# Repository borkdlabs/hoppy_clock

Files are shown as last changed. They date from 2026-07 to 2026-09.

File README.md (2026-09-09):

# hoppy_clock






STM32-based alarm clock and RGB lamp: custom alarms wake you with light and your
own songs, configured over USB from the browser or a Python tool.

<a href="https://www.pcbway.com">
  PCBWay Logo
</a>

💚 Sponsored by **[PCBWay](https://www.pcbway.com)**, who provided the bare PCBs
and solder paste stencil for the v0.1.0-alpha boards -
see [Acknowledgements](#acknowledgements).

---

<details markdown="1">
  <summary>Table of Contents</summary>

<!-- TOC -->
* [hoppy_clock](#hoppy_clock)
  * [1 Overview](#1-overview)
    * [1.1 Bill of Materials (BOM)](#11-bill-of-materials-bom)
    * [1.2 Block Diagram](#12-block-diagram)
    * [1.3 Pin Configurations](#13-pin-configurations)
    * [1.4 Clock Configurations](#14-clock-configurations)
  * [2 Board Specifications](#2-board-specifications)
    * [2.1 Connectors](#21-connectors)
    * [2.2 Switches & Jumpers](#22-switches--jumpers)
    * [2.3 LEDs](#23-leds)
    * [2.4 Test Pads](#24-test-pads)
    * [2.5 Power Supply](#25-power-supply)
    * [2.6 Speaker](#26-speaker)
  * [3 Firmware](#3-firmware)
    * [3.1 User Button Controls](#31-user-button-controls)
    * [3.2 USB Configuration](#32-usb-configuration)
      * [3.2.1 Web App](#321-web-app)
      * [3.2.2 Python Tool](#322-python-tool)
    * [3.3 Light Looks](#33-light-looks)
    * [3.4 Sounds](#34-sounds)
    * [3.5 Firmware Update (DFU)](#35-firmware-update-dfu)
  * [4 Development](#4-development)
    * [4.1 Web App](#41-web-app)
    * [4.2 Deployment](#42-deployment)
  * [Acknowledgements](#acknowledgements)
  * [Third-Party Licenses](#third-party-licenses)
<!-- TOC -->

</details>

---

## 1 Overview

| Top | Bottom |
|:---:|:---:|
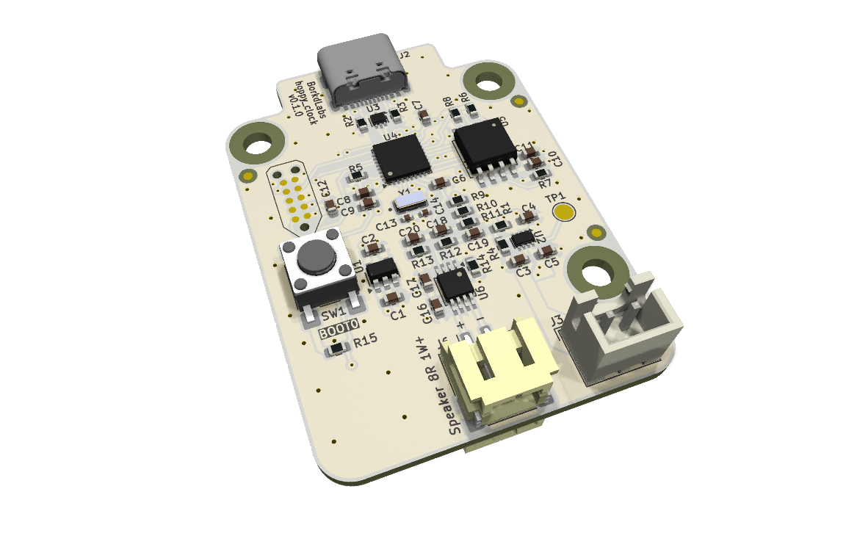
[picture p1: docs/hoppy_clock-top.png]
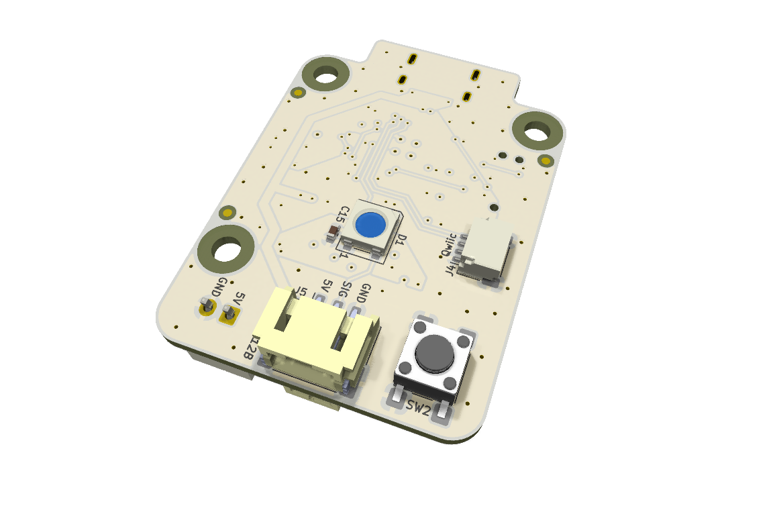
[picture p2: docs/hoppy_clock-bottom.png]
|  |  |

**Features**:

- ⏰ **Alarms**: up to 64, each either weekly (any set of weekdays) or monthly (a
  day of the month) at a chosen time. Every alarm has its own light look, sound,
  volume fade-in and auto-quiet timeout.
- 💡 **Lamp**: the single button toggles a warm lamp look on/off, the "off"
  state can settle to a dim ambient rather than fully dark.
- ✨ **Lights**: parametric looks (`solid`, `rainbow`, `sweep`, `breathe`)
  rendered across the onboard LED and any chained via the `WS2812B breakout`
  connector, every one of them with its own fade and optional flicker.
- 🔊 **Sounds**: two slots, ~4 minutes each at the default 16 kHz (16-bit PCM,
  sample rate is selectable up to 48 kHz), streamed from flash. Alarms play them
  with an optional fade-in.
- 🔋 **Low power**: the MCU sleeps between events and drops into STOP2 once the
  system is idle, waking on the next alarm or a button press (useful on backup
  supply).
- 🖥️ **Configuration**: nothing is hard-coded, the board takes its settings over
  USB from the [web app](https://borkdlabs.github.io/hoppy_clock/) (Chrome or
  Edge, nothing to install).
- 🔴 **Clock-unset cue**: if the time has never been set (for example, after a
  full power loss), the onboard LED (index 0) blinks dim red and alarms are
  blocked from triggering until the clock is set.

### 1.1 Bill of Materials (BOM)

| Manufacturer Part Number | Manufacturer | Description | Quantity | Notes |
|---|---|---|---:|---|
| STM32L432KC | STMicroelectronics  | 32-bit MCU | 1 | |
| WS2812B | (Various) | PWM Addressable RGB LED | 1 | |
| PAM8302AAS | Diodes Incorporated | Audio Amplifier | 1 | |
| W25Q128JVSIQ | Winbond Electronics | 128 Mbit NOR Memory | 1 | |
| Generic Push Button | | | 1 | |

### 1.2 Block Diagram

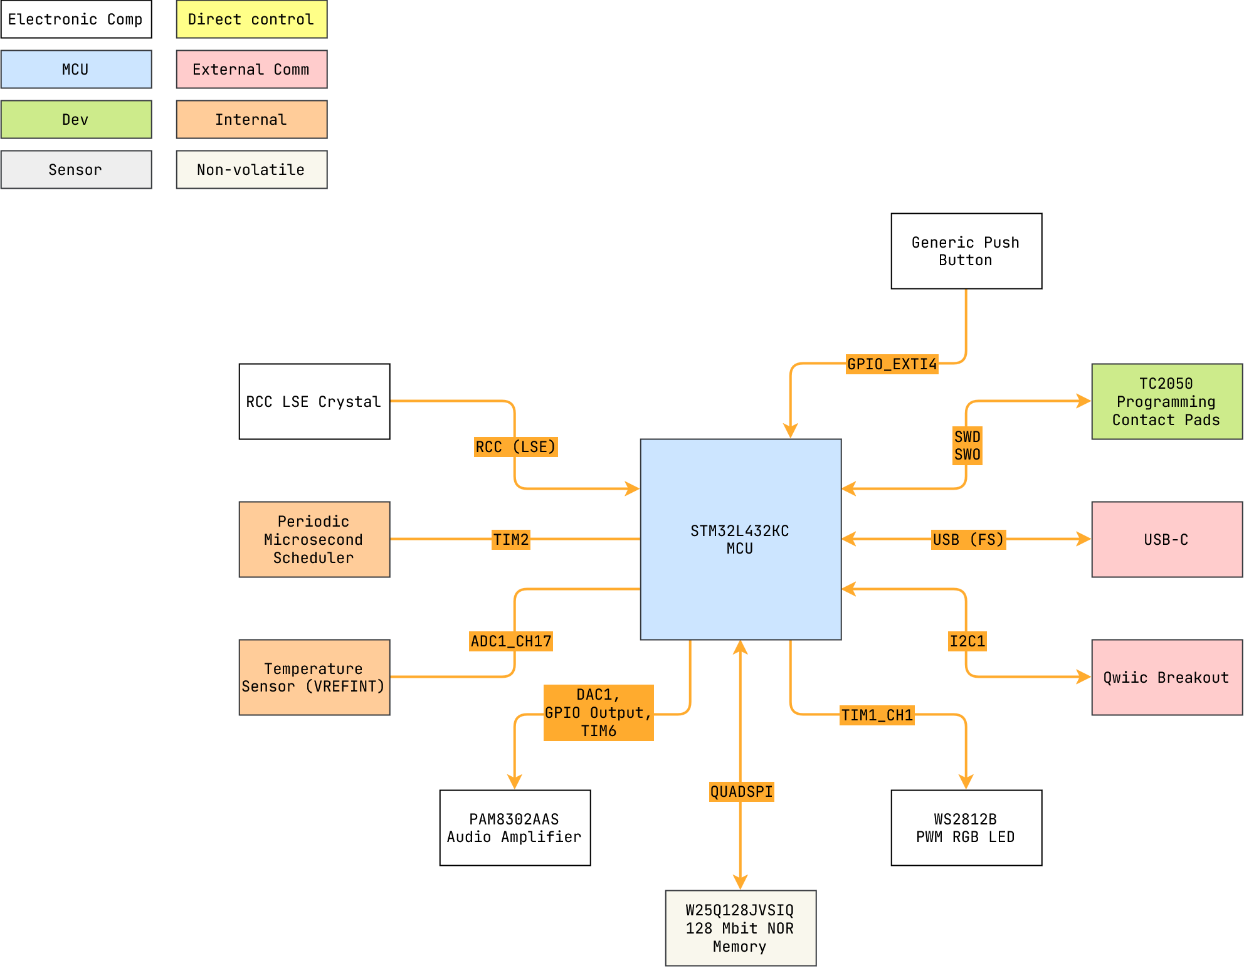
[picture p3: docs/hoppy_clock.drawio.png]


> Drawio file here: [hoppy_clock.drawio](docs/hoppy_clock.drawio).

### 1.3 Pin Configurations

<details markdown="1">
  <summary>CubeMX Pinout</summary>

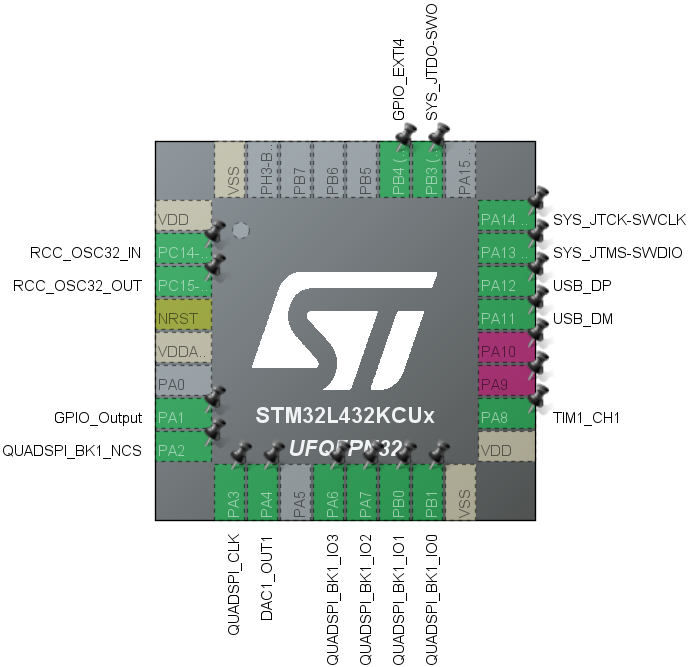
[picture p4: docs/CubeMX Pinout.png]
CubeMX Pinout.png


</details>

<details markdown="1">
  <summary>Pin & Peripherals Table</summary>

| STM32L432KC | Peripheral | Config | Connection | Notes |
|---|---|---|---|---|
| PA14 | `SYS_JTCK-SWCLK`  | | TC2050 SWD Pin 4: `SWCLK` | |
| PA13 | `SYS_JTMS-SWDIO`  | | TC2050 SWD Pin 2: `SWDIO` | |
| PB3 | `SYS_JTDO-SWO` | | TC2050 SWD Pin 2: `SWO` | |
| | `TIM2_CH1` | PWM no output | Scheduling | Scheduler timer. |
| | `TIM6` | TRGO update event | | `DAC1_OUT1` TRGO. |
| | `ADC1` `VREFINT`  | Scan conversion mode | VDDA Sense | Configured in ADC1 rank 1. |
| | `ADC1_IN17` | Scan conversion mode | Temperature Sensor Channel | Configured in ADC1 rank 2. |
| PA10 | `Reserved` | 115200 bps | GPIO Breakout: (ie Qwiic: `I2C1_SDA`) | Reserved GPIO breakout (PA10). |
| PA9 | `Reserved` | 115200 bps | GPIO Breakout: (ie Qwiic: `I2C1_SCL`) | Reserved GPIO breakout (PA9). |
| PA11 | `USB_DM` | Device (FS) | USB-C D- | |
| PA12 | `USB_DP` | Device (FS) | USB-C D+ | |
| PA8 | `TIM1_CH1` | PWM Generation CH1 | WS2812B-2020 Pin: `DIN` | DIN pin number depends on IC variant. |
| PA4 | `DAC1_OUT1` | | PAM8302AAS Input Circuit | |
| PA1 | `GPIO_Output` | Hardware pull-down | PAM8302AAS Pin 1: `SD` | |
| PA3 | `QUADSPI_CLK` | | W25Q128JVSIQ Pin 6: `CLK` | |
| PA2 | `QUADSPI_BK1_NCS` | Hardware pull-up | W25Q128JVSIQ Pin 1: `CS` | |
| PB1 | `QUADSPI_BK1_IO0` | | W25Q128JVSIQ Pin 5: `IO0` | |
| PB0 | `QUADSPI_BK1_IO1` | | W25Q128JVSIQ Pin 2: `IO1` | |
| PA7 | `QUADSPI_BK1_IO2` | Hardware pull-up | W25Q128JVSIQ Pin 3: `IO2` | Hardware pull-up for potential bringup from SPI single-line. |
| PA6 | `QUADSPI_BK1_IO3` | Hardware pull-up | W25Q128JVSIQ Pin 7: `IO3` | Hardware pull-up for potential bringup from SPI single-line. |
| PB4 | `GPIO_EXTI4` | Hardware pull-up | Generic Push Button Active Low pin | |

</details>

### 1.4 Clock Configurations

```
4 MHz Multi-Speed Internal (MSI), LSE-trimmed
 -> Phase-Locked Loop Main (PLL)
 -> 80 MHz SYSCLK
 -> 80 MHz HCLK
     -> 80 MHz APB1 (Maxed) -> 80 MHz APB1 Timer
     -> 80 MHz APB2 (Maxed) -> 80 MHz APB2 Timer
 -> PLLSAI1 -> 48 MHz USB & ADC clock

32.768 kHz Low Speed External (LSE)
     -> 32.768 kHz RTC
     -> Disciplines the MSI (MSI PLL mode)
```

---

## 2 Board Specifications

### 2.1 Connectors

Connectors fixed by hardware (PCB traces or the connector itself).

| Connector | Ref | Description |
|---|:---:|---|
| `Tag-Connect TC2050` | J1  | SWD programming/debug connector |
| `USB-C` | J2  | USB-C 5 V power & data source |
| `Backup supply` | J3  | 1x2 JST XH (2.5 mm pitch), Pin 1: Backup 5 V, Pin 2: ground |
| `Qwiic` | J4  | 1x4 JST SH, Pin 1: ground, Pin 2: 3.3 V, Pin 3: SDA, Pin 4: SCL |
| `WS2812B breakout` | J5  | 1x3 JST PH, Pin 1: 5 V, Pin 2: DOUT, Pin 3: ground |
| `Speaker` | J6  | 1x2 JST PH, Pin 1: OUT+, Pin 2: OUT- |

### 2.2 Switches & Jumpers

User controllable hardware and/or firmware driven inputs.

| Switch/Jumper  | Ref | Description |
|---|:---:|---|
| `BOOT0 button` | SW1 | Push to pull `BOOT0` high |
| `User button`  | SW2 | Generic 6 mm SMD button |

### 2.3 LEDs

LEDs used to show board status and/or user controllable.

| LED | Mark | Description |
|---|---|---|
| `WS2812B LED` | None | RGB addressable LED |

### 2.4 Test Pads

| Test Point | Ref | Description |
|---|:---:|---|
| `TPS2116 ST` | TP1 | `ST` pin from onboard TPS2116 |

### 2.5 Power Supply

By default, the board is powered from the `USB-C` 5 V source. An onboard TPS2116
priority power mux allows a backup 5 V supply to be connected via the
`Backup supply` connector (for example, a regulated battery pack output). If the
USB-C supply drops below the mux threshold, the TPS2116 automatically switches
the board over to the backup supply and switches back when USB-C power returns.
The mux status pin (`ST`) is exposed on the `TPS2116 ST` test pad and is pulled
low whenever the backup supply is in use, allowing a probe to detect the active
source during development/testing.

TPS2116 4.1 V switchover threshold logic:

```
PR1 = VIN1 * R_bot / (R_top + R_bot)
    = VIN1 * 220k / (680k + 220k)
    = VIN1 * 0.2444

VIN1(th) = 1V * (R_top + R_bot) / R_bot
         = 1V * (680k + 220k) / 220k
         = 4.09 V

Tolerance: +-0.08V
min: (1V - 0.08V) * 4.0909 = 3.76 V
max: (1V + 0.08V) * 4.0909 = 4.42 V
```

External LEDs on the `WS2812B breakout` connector are powered from USB (VBUS)
directly, not the priority power mux in order to prevent excessive battery drain
during a power outage. The single onboard LED is on the priority power mux
supply, so it remains available for minimum operation on battery power.

### 2.6 Speaker

An 8 ohm, >= 1 W speaker can be connected via the `Speaker` connector. The
amplifier output is bridge-tied (BTL): both terminals are driven, so neither may
be connected to ground.

---

## 3 Firmware

The firmware is fixed, all user settings (time, alarms, light looks, the lamp,
sounds and the LED count) live in the W25Q NOR flash and are written over USB at
runtime. Settings survive resets (the clock's time is kept in the STM32 backup
domain), as long as the board stays powered from USB-C or the backup supply. A
full power loss resets the clock (see the clock-unset cue above). A flash `wipe`
returns the unit to a clean state.

Stored settings carry a format version. A firmware update that changes that
format resets them: rather than misread an older image, the board falls back to
empty defaults, comes up on its built-in lamp look and needs reconfiguring.

### 3.1 User Button Controls

| Action | While idle | While an alarm is ringing |
|---|---|---|
| Short press | Toggle the lamp on/off | (ignored) |
| Long press  | Play / stop the button song | Silence the alarm |

### 3.2 USB Configuration

The board enumerates as a USB CDC virtual serial port and speaks a small framed
command protocol (`firmware/Core/Inc/usb_cmd.h`). Two hosts implement it:

| Host | Runs on |
|---|---|
| [`software/main.py`](software/main.py) | Any OS with Python 3 |
| [Web app](https://borkdlabs.github.io/hoppy_clock/) | Chrome or Edge on desktop, no install |

Both open the same serial port and only one program may hold it at a time.

**Connecting:** When the clock is idle and off USB it deep-sleeps (STOP2) and
deliberately presents as *detached*, so plugging into a host shows no device at
first. To connect:

1. Plug the USB-C cable into the host.
2. **Press the button once** to wake the clock. It re-attaches and enumerates as
   a virtual serial port (the same short press also toggles the lamp as usual,
   harmless).
3. Run the Python tool.

If the clock is already awake (in use, ringing, an alarm just fired, or the lamp
is showing a continuously animating look), it enumerates the moment you plug in,
with no press needed. Unplugging or the host going to sleep allows the system to
return to deep sleep.

> **Why a button press?** The clock cannot tell a data host (a PC) from a plain
> USB-C charger or power bank, both simply present 5 V with no reliable way to
> distinguish them until an enumeration that only a real host answers. Waking
> and enumerating on every plug-in would spend energy for the majority of the
> time the port is used only to charge or power the unit and risks staying awake
> on a battery pack it mistook for a host. Gating USB behind a deliberate button
> press ties enumeration to a real intent to configure and lets the clock stay
> in its lowest-power state whenever it is merely being powered. Firmware itself
> is flashed over SWD (the `TC2050` header), independent of this path.

#### 3.2.1 Web App

<https://borkdlabs.github.io/hoppy_clock/>

A single static page that drives the port through the
[Web Serial API](https://developer.mozilla.org/en-US/docs/Web/API/Web_Serial_API),
so there is nothing to install beyond the OS's own CDC driver. It needs **Chrome
or Edge on desktop** (Windows, macOS or Linux); Firefox, Safari and mobile
browsers do not implement Web Serial and the page says so rather than
half-working.

Press *Connect* and pick the STM32 virtual COM port (`0483:5740`). Permission is
granted per site and remembered, so later visits reopen that port on their own.

#### 3.2.2 Python Tool

```bash
cd software
python main.py <command> [options]     # add -p COM7 (or /dev/ttyACM0) to pick the port
```

> Needs Python 3 with `pyserial` (`pip install -r software/requirements.txt`),
> MP3 uploads additionally need `ffmpeg` on the `PATH`. See top docstring in
> `main.py` for more information.

| Command | Description |
|---|---|
| `set-time` | Sync the RTC to the host's local time |
| `add-alarm` / `set-alarm` | Add an alarm (e.g. `--at 08:00 --days weekdays`) / replace all with one |
| `remove-alarm N` / `clear-alarms` | Delete one alarm by index / delete all |
| `list-alarms` | Show alarms, lights, the lamp and LED count |
| `set-light` | Define a light look (`--effect`, `--fade`, `--curve`, `--flicker`) |
| `set-lamp` | Choose the on/off lamp idle looks |
| `set-led-count N` | Set the number of chained LEDs |
| `upload-sound` | Store a sound from a WAV/MP3 file or a synthesized tone |
| `play-sound` / `stop-sound` | Play / stop a stored sound now |
| `set-button-song` | Set which sound the long-press plays |
| `wipe` | Factory-reset the flash (`--full` also scrubs the audio) |

Run `python main.py --help` (or `<command> --help`) for the full option list.

### 3.3 Light Looks

A light look is not a stored animation but a handful of parameters the firmware
renders live across the whole chain. Up to 16 are stored; alarms and the two
lamp idle states each reference one by id. Every look sets a base colour and a
master brightness, then picks an effect:

| Effect | Renders | Cycle time | Spread |
|---|---|---|---|
| `solid` | The whole strip held at one colour  | - | - |
| `rainbow` | The HSV hue wheel, cycling | Time per turn | Hue step per LED (0 = strip as one colour) |
| `sweep` | A lit band travelling over darkness | Time per pass | Band width, in LEDs |
| `breathe` | The colour swelling and receding | Time per breath | - |

`solid` settles and holds as an idle. The other three loop until something else
is played.

The same three settings apply to all four alike:

| Setting | Does |
|---|---|
| `fade` | Time this look takes to fade in over whatever is already lit |
| `curve` | Shape of that fade: `linear` (constant rate) or `ease` (gentle at both ends) |
| `flicker` | Amplitude of a random brightness dip, redrawn several times a second |

**A fade runs on entry only.** Every transition uses the fade of the look
arriving, never of the one leaving: playing a look is the only thing that starts
a fade, and by then the previous look is already on its way out. So the `fade`
on a `rainbow` decides how that rainbow appears and has no say in what happens
when something later replaces it.

To fade a look both in and out, set the fade on that look **and** on whatever
replaces it. A lamp that eases up and back down over two and a half seconds:

| Look | Effect | Brightness | Fade | Curve  |
|---|---|---|---|---|
| Lamp on  | `rainbow` | 200 | 2500 | `ease` |
| Lamp off | `solid` | 0 | 2500 | `ease` |

Give the lamp-off look a fade of 0 instead, and it cuts to black the instant the
button is pressed, no matter how long the rainbow's own fade is. A fade of 0
always means "no fade, show this look now".

The look being faded away from is held as a still frame, so a `rainbow` stops
cycling the moment it is replaced and dims from whichever hues it had reached.

Flicker is a texture rather than a shape, so it is set separately from the
curve, and the two combine freely. Unlike the fade it never ends, which is what
makes a `solid` warm white read as a candle instead of a lamp.

**A continuously animating look keeps the board out of deep sleep.** Only a
`solid` look with `flicker` 0 ever finishes: once its fade lands, it settles on
a fixed colour, stops rendering, and lets the MCU drop into STOP2. `rainbow`,
`sweep` and `breathe` loop for as long as they are showing, and any `flicker`
above 0 never stops, so a look of either kind holds the board in light sleep
instead. Two consequences follow:

- **Power.** Light sleep gates the core but keeps the clocks and peripherals
  live, so the board sits at run current rather than the microamps STOP2 draws.
  That matters most on the backup supply, where a permanently animated lamp look
  is a far heavier load than a settled `solid` one.
- **USB.** A board that never deep-sleeps never detaches either, so it
  enumerates the moment it is plugged in with no button press needed (see
  [3.2 USB Configuration](#32-usb-configuration)). Parking the lamp on an
  animated look is a way to keep it permanently connectable while configuring.

The clock-unset warning blink holds the board awake in the same way, until the
time is set.

### 3.4 Sounds

Two slots hold one sound each, 7.5 MiB apiece, in the same NOR flash as the
settings. Alarms reference a slot by id, and the long press plays one.

**The source file's own format does not matter.** Uploading anything that is not
already raw PCM runs it through `ffmpeg`, which decodes and resamples it to mono
at the rate and sample format *you* pick:

```bash
ffmpeg -i song.mp3 -ac 1 -ar <rate> -f s16le|u8 -
```

A 320 kbps 44.1 kHz stereo MP3 and a 96 kbps mono one land on the board as the
same shape of data, so there is nothing to read off a file to decide with. What
gets stored is the raw blob plus the rate and format it was made at, the
firmware reads those back at playtime and clocks the DAC accordingly.

So the two settings are a trade between quality and how much fits in a slot:

| Rate | `s16` (2 B/sample) | `u8` (1 B/sample) |
|---|---|---|
| 8000 | 8m 11s | 16m 23s |
| 16000 (default) | 4m 05s | 8m 11s |
| 22050 | 2m 58s | 5m 56s |
| 32000 | 2m 02s | 4m 05s |
| 48000 (max) | 1m 21s | 2m 43s |

Two things to weigh:

- **The speaker is the real ceiling.** Output is a 12-bit DAC into a PAM8302A
  driving a little speaker, so 16 kHz already covers about as much bandwidth as
  it can reproduce. Higher rates mostly spend slot space on detail that never
  reaches the air.
- **`u8` halves the size but adds hiss.** Eight-bit quantization is audible on
  anything sustained. It suits short effects and tones, not music.

In practice leave both on their defaults (`s16` at 16000 Hz) and use the trim
option to fit a long track, rather than dropping quality to make it fit. Reach
for `u8` or a lower rate only when a long clip matters more than how it sounds.

### 3.5 Firmware Update (DFU)

This flashes new *firmware* (not settings, those use the USB tool above).
Normally firmware is programmed over SWD (the `TC2050` header). Without a
debugger, the STM32L432's built-in USB bootloader (DFU) flashes it over the same
USB-C port.

`BOOT0` is sampled only at power-up, so DFU has to be entered on a fresh cold
boot with the button held:

1. **Remove all power**, unplug USB **and** anything on the `Backup supply`
   connector. A backup supply keeps the MCU running, so plugging in USB would
   not be a cold boot and `BOOT0` would never be re-sampled. (With no backup
   supply attached, USB is the only source and this is automatic.)
2. Hold the `BOOT0` button.
3. While still holding it, connect USB-C to the computer. The board powers up
   into the bootloader and enumerates as **STM32 BOOTLOADER** (DFU, USB
   `0483:DF11`). Release the `BOOT0` button.
4. Flash the image to the flash base `0x08000000`, then restart into it with
   your DFU tool/software.

---

## 4 Development

### 4.1 Web App

[`webapp/`](webapp) is plain ES modules with no build step, no bundler and no
dependencies, it is served exactly as it sits in the repository. Web Serial only
runs in a secure context and `http://localhost` counts as one, so a static
server is enough and no HTTPS setup is needed:

```bash
cd webapp
python -m http.server 8000
```

Then open <http://localhost:8000> in Chrome or Edge.

| Path | What it is |
|---|---|
| `index.html`, `css/style.css` | Page and styling |
| `js/alarms.js` | Packed alarm records, mirrors `manifest.h` |
| `js/app.js` | Tab switching and the wiring behind every card |
| `js/device.js` | Port lifecycle, transactions, manifest read/write |
| `js/lights.js` | Packed light looks, mirrors `manifest.h` |
| `js/sounds.js` | Sound slots and the decode/encode upload path |
| `js/protocol.js` | Framing and CRC-8, mirrors `firmware/Core/Inc/usb_cmd.h` |
| `dev/` | The helpers below, stripped from the published site |

**Working without a board.** The offline checks exercise the framing and
transaction layers against a fake CDC port, covering the happy path, error
statuses, command timeouts and a mid-command unplug:

```bash
cd webapp/dev
node test-device.mjs
```

For the UI itself, paste
[`dev/inject-fake-port.js`](webapp/dev/inject-fake-port.js) into the browser
console with the page open. It stubs `navigator.serial.requestPort` with a clock
whose RTC runs 47 s fast, so the connect flow, the drift readout and the sync
button can all be driven dry. More in [`webapp/dev/`](webapp/dev/README.md).

A protocol change touches three implementations, keep them in step:
`firmware/Core/Inc/usb_cmd.h`, `software/main.py` and `webapp/js/`
(`protocol.js` for the framing, `alarms.js`, `lights.js` and `sounds.js` for the
record layouts).

### 4.2 Deployment

[`.github/workflows/pages.yaml`](.github/workflows/pages.yaml) publishes the app
to GitHub Pages on every push to `main` touching `webapp/`. It runs
`node --check` over each module and the offline checks above, copies `webapp/`
to the site root minus `dev/`, then deploys. Pull requests build and test but do
not publish and the workflow can also be started by hand (*Actions -> Pages ->
Run workflow*).

The repository's Pages source must be set to **GitHub Actions**
(*Settings -> Pages -> Build and deployment -> Source*).

---

## Acknowledgements

<a href="https://www.pcbway.com">
  PCBWay Logo
</a>

This project is sponsored by [PCBWay](https://www.pcbway.com), whose PCB
manufacturing services are essential in producing high-quality prototypes for
its development. Their support ensures reliable boards that meet the project's
demands.

**Why PCBWay?**

PCBWay stands out for their exceptional services and commitment to the
community:

- **PCB manufacturing**: multilayer, rigid-flex and other advanced fabrication.
- **PCB assembly**: soldering, component sourcing and assembly.
- **Other services**: CNC machining and 3D printing, for projects that need more
  than a board.
- **Fast turnaround**: quick production times that keep a project on schedule.
- **Open source and education**: they sponsor projects and publish tutorials,
  videos and documentation for developers and hobbyists.
    - This commitment to education and open-source advocacy was a key factor in
      choosing them as a partner 🙂.

Their dedication to professional-grade services and fostering innovation makes
PCBWay an invaluable partner in bringing this project to life.

---

## Third-Party Licenses

This project uses the following open-source software components:

- **STM32Cube HAL**, STMicroelectronics.
    - Licensed under the `3-Clause BSD License`.
        - See
          [`LICENSE.txt`](firmware/Drivers/STM32L4xx_HAL_Driver/LICENSE.txt).

> STMicroelectronics are trademarks of their respective owners. Use of these
> names does **not** imply any endorsement by the trademark holders.

> The PCBWay name and logo are trademarks of PCBWay, reproduced with their
> permission to acknowledge their sponsorship of this project.

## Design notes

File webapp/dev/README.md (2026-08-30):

# Development helpers

Not part of the deployed site, the Pages workflow strips this directory before
publishing.

## Serve the app locally

Web Serial needs a secure context, and `http://localhost` counts as one, so no
HTTPS setup is required:

```bash
cd webapp
python -m http.server 8000
```

Then open <http://localhost:8000> in Chrome or Edge.

## `test-device.mjs`

Exercises the framing, transaction and manifest layers against a fake CDC port,
with no hardware attached. Covers the happy path, error statuses, command
timeouts, mid-command unplug, the packed alarm, light and sound records, and
editing alarms, light looks, the lamp ids, the LED count and the button song
without disturbing the rest of the manifest. Sound upload is covered too: PCM
encoding, a CRC-32 check against a known vector, the chunked stream arriving
byte for byte, and a cancel part-way leaving nothing committed. Clearing the
alarm table, lighting a single LED, and both wipe scopes are covered too.

```bash
cd webapp/dev
node test-device.mjs
```

## `inject-fake-port.js`

Paste into the browser console (or evaluate through DevTools) while the app is
open. It replaces `navigator.serial.requestPort` with a stub clock whose RTC
runs 47 s fast, whose manifest holds two alarms and two light looks, and whose
first sound slot holds a 10 s blob, so every tab can be driven without a board.
It accepts uploads and wipes as well: playback commands land on
`window.__lastPlayback` rather than making a noise, a committed upload lands on
`window.__lastUpload`, a wipe on `window.__lastWipe`, and a lit LED on
`window.__lastLed`. The stub's manifest is left on
`window.__fakeConfig`, which is the quickest way to see what a save actually
wrote.

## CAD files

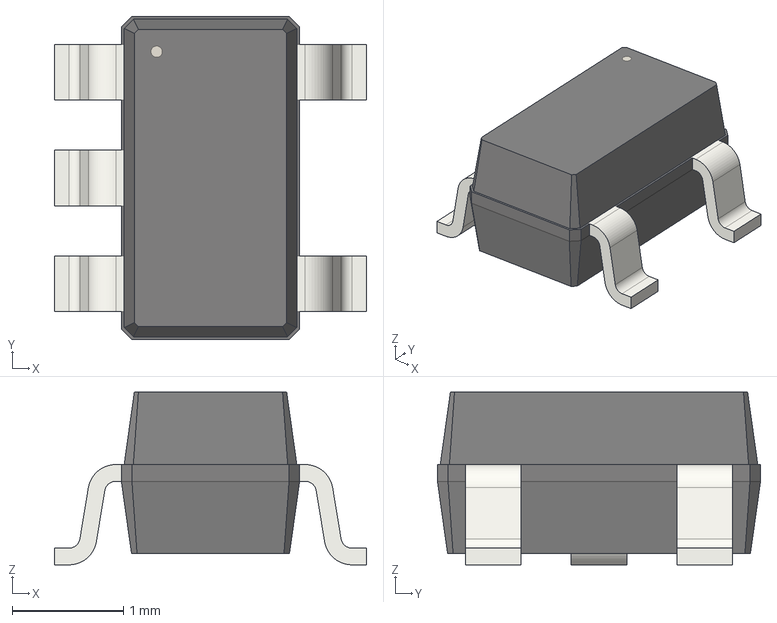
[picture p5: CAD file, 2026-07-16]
hardware/component_local/model_3d/0_standard/SOT-23-5.step
2.80 x 2.90 x 1.55 mm

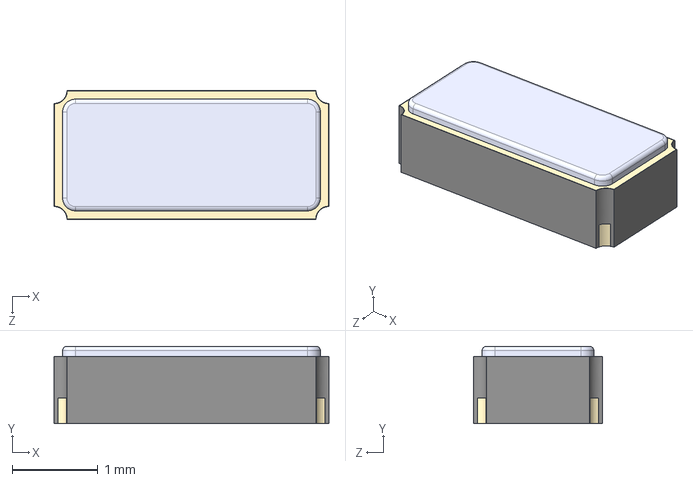
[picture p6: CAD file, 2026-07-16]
hardware/component_local/model_3d/common/ecs_ecx-34r.step
3.20 x 0.9 x 1.50 mm

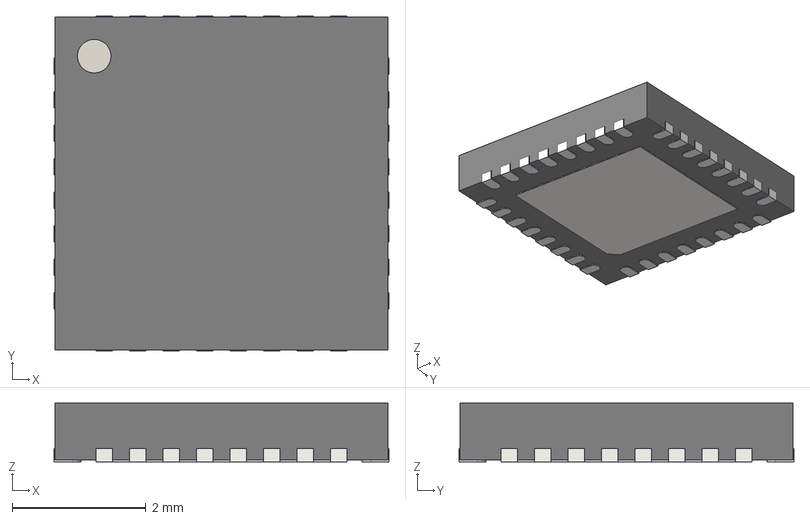
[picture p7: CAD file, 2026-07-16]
hardware/component_local/model_3d/stm32l4/QFN-32-1EP_5x5mm_P0.5mm_EP3.3x3.3mm.step
5.00 x 5.00 x 0.875 mm

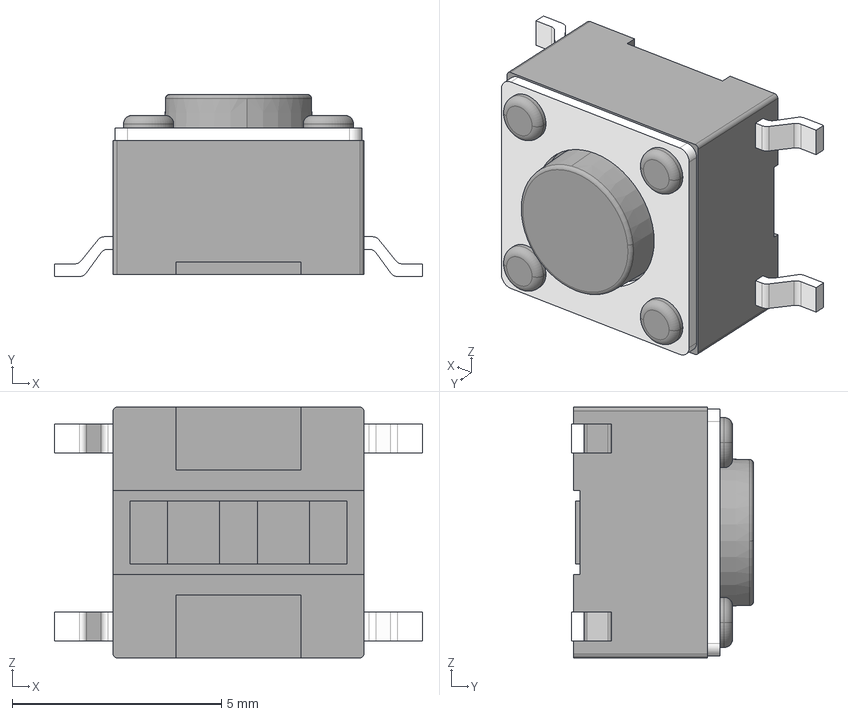
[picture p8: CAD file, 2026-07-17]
hardware/component_local/model_3d/switch/swt0310-043025gsa.stp
8.80 x 4.35 x 6.00 mm

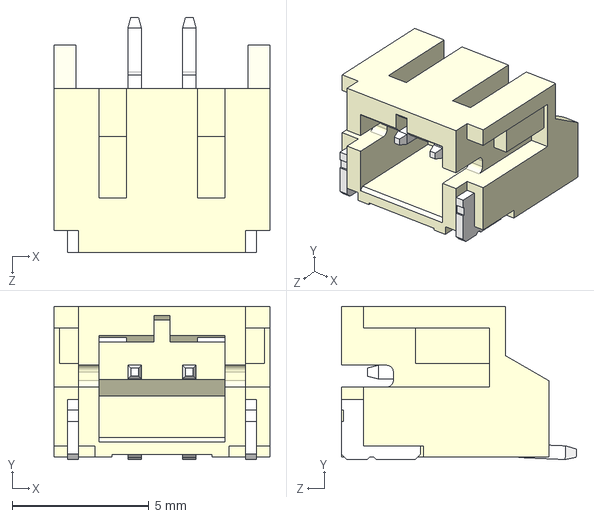
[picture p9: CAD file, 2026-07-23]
hardware/component_local/model_3d/z_other/S2B-PH-SM4-TB.STEP
7.90 x 5.60 x 8.60 mm

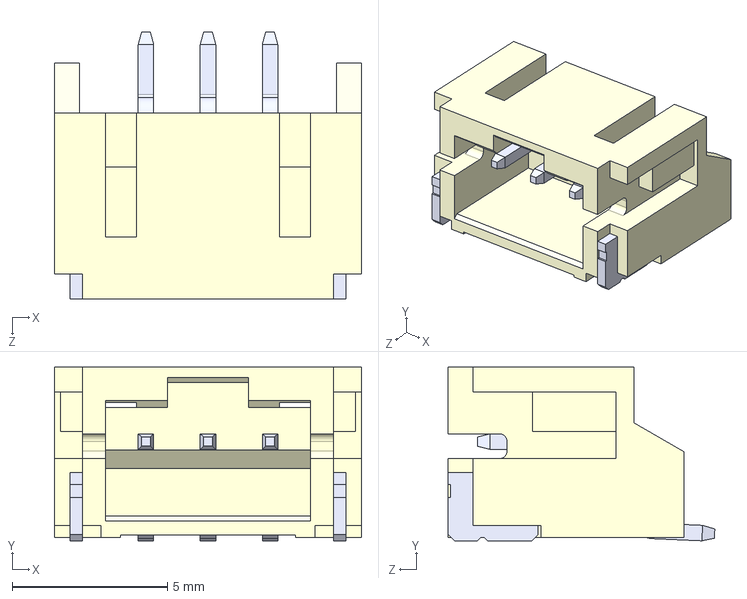
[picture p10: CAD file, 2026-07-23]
hardware/component_local/model_3d/z_other/S3B-PH-SM4-TB.STEP
9.90 x 5.60 x 8.60 mm

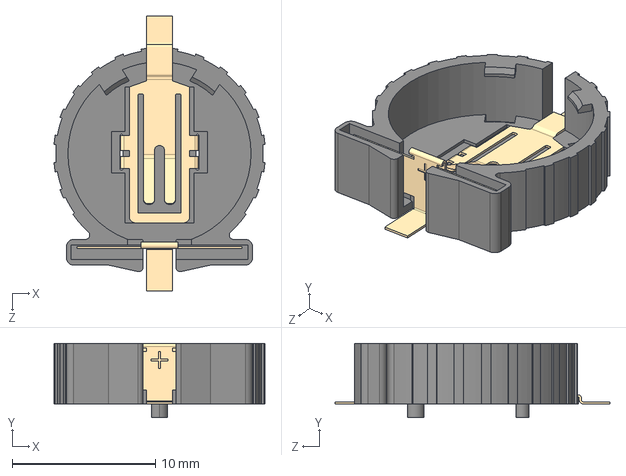
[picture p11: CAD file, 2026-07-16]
hardware/component_local/model_3d/common/S8411-45R.step
14.7 x 5.20 x 19.2 mm

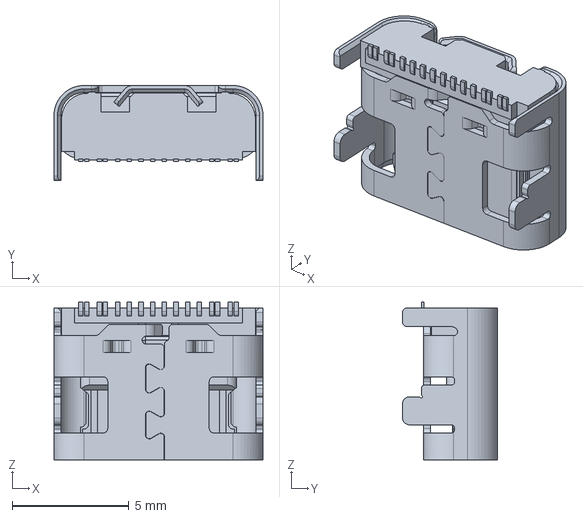
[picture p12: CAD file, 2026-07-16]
hardware/component_local/model_3d/common/2171790001.stp
8.94 x 4.06 x 6.75 mm

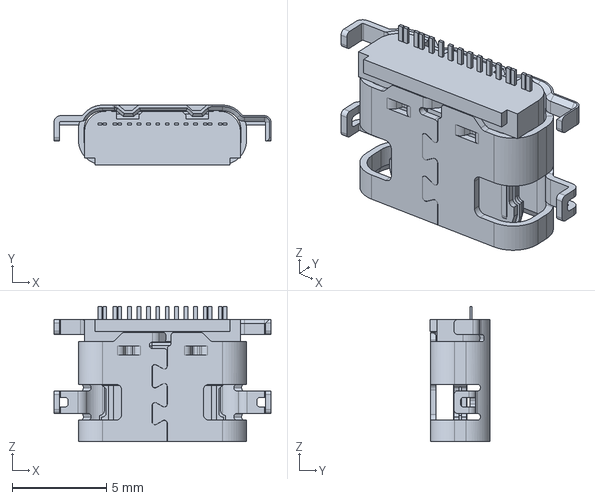
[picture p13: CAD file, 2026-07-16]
hardware/component_local/model_3d/common/2169900001.stp
11.5 x 3.18 x 7.20 mm

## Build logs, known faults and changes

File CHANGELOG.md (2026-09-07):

# Changelog

---

<details markdown="1">
  <summary>Table of Contents</summary>

<!-- TOC -->
* [Changelog](#changelog)
  * [v0.1.0-alpha (2026-07-25)](#v010-alpha--2026-07-25-)
  * [v0.1.0 (TBD)](#v010--tbd-)
<!-- TOC -->

</details>

---

## [v0.1.0-alpha (2026-07-25)](https://github.com/borkdlabs/hoppy_clock/releases/tag/v0.1.0-alpha)

- Pre-release 4-layer board variant (hardware-focused release).
    - Short-term pre-release board bring-up/testing release.
- Order date: 2026/07/21.
    - Note: Minor DNP status changes are included (changes made after order
      placement and before official release). No Gerber files are affected.

Manual corrections:

1. The silkscreen labeling the pins on the `WS2812B breakout` connector is
   incorrect (**_5 V and ground are flipped!_**). The true pinout is: 1x3 JST
   PH, Pin 1: ground, Pin 2: DOUT, Pin 3: 5 V.
    - The silkscreen represents the intended design (matching most WS2812B LED
      strip pinouts), but the connector pinout was ordered incorrectly. To be
      corrected in the following release.
2. The backup supply via the `Backup supply` connector should not be used unless
   jumpered.
    - The TPS2116DRL is missing something to help pull VIN1 low below the 1 V
      threshold in time of a supply switchover, leading to power issues when
      connecting to `Backup supply`. Manual fixes from quickest to best:
        1. Add a resistor light pull-down to VIN1 allowing a reliable drop of
           VIN1 to below 1 V.
        2. Add a divider circuit for a custom threshold:
            - Rewire PR1 as the divider center tap.
            - MODE to VIN1 directly (currently tied to VIN1 through PR1 pad)
            - Tested with a 76.8k / 22.1k divider (4.48 V threshold, less ideal
              due to very little upper tolerance).
3. _Optional_: The `WS2812B breakout` is currently wired to supply external
   off-board WS2812B LEDs using the TPS2116DRL post-mux supply. Cut the 3
   thermal relief traces on the 5 V net of the `WS2812B breakout` and jumper
   wire to the USB (VBUS) pour to prevent excessive backup supply drain.

---

## [v0.1.0 (TBD)](https://github.com/borkdlabs/hoppy_clock/releases/tag/v0.1.0)

- 4-layer board variant.
    - Moderate confidence near production release.
- **Modifications:**
    - Fix `WS2812B breakout` connector pinout to match silkscreen and expected
      WS2812B LED strip pinouts.
        - Update `README.md` docs accordingly.
    - Minor silkscreen cleanup.
    - Fix power switching, add voltage divider on TPS2116DRL for an improved
      supply mux threshold.
        - Previously used the default 1 V threshold.
        - VIN1 to 680k / 220k to ground voltage divider for 4.1 V threshold.
            - Pin PR1 disconnected from VIN1, center-tapped to voltage divider.
            - Pin MODE disconnected from PR1/VIN1, retraced directly to VIN1.
    - Add copper clearance on the top layer below the USB-C connector.
    - Add 1 mm fillet on USB-C area neck.
    - Fix the bad release link in `CHANGELOG.md` for v0.1.0-alpha.
    - Swap THT `User button` to match onboard `BOOT0 button` SMD part.
    - Move SMD right angle connectors `WS2812B breakout` and `Speaker` closer to
      edge cut for better wiring.
    - Split the `WS2812B breakout` to supply external off-board WS2812B LEDs via
      USB (VBUS) only to prevent excessive backup supply drain.
- Order date: **_TBD_**.

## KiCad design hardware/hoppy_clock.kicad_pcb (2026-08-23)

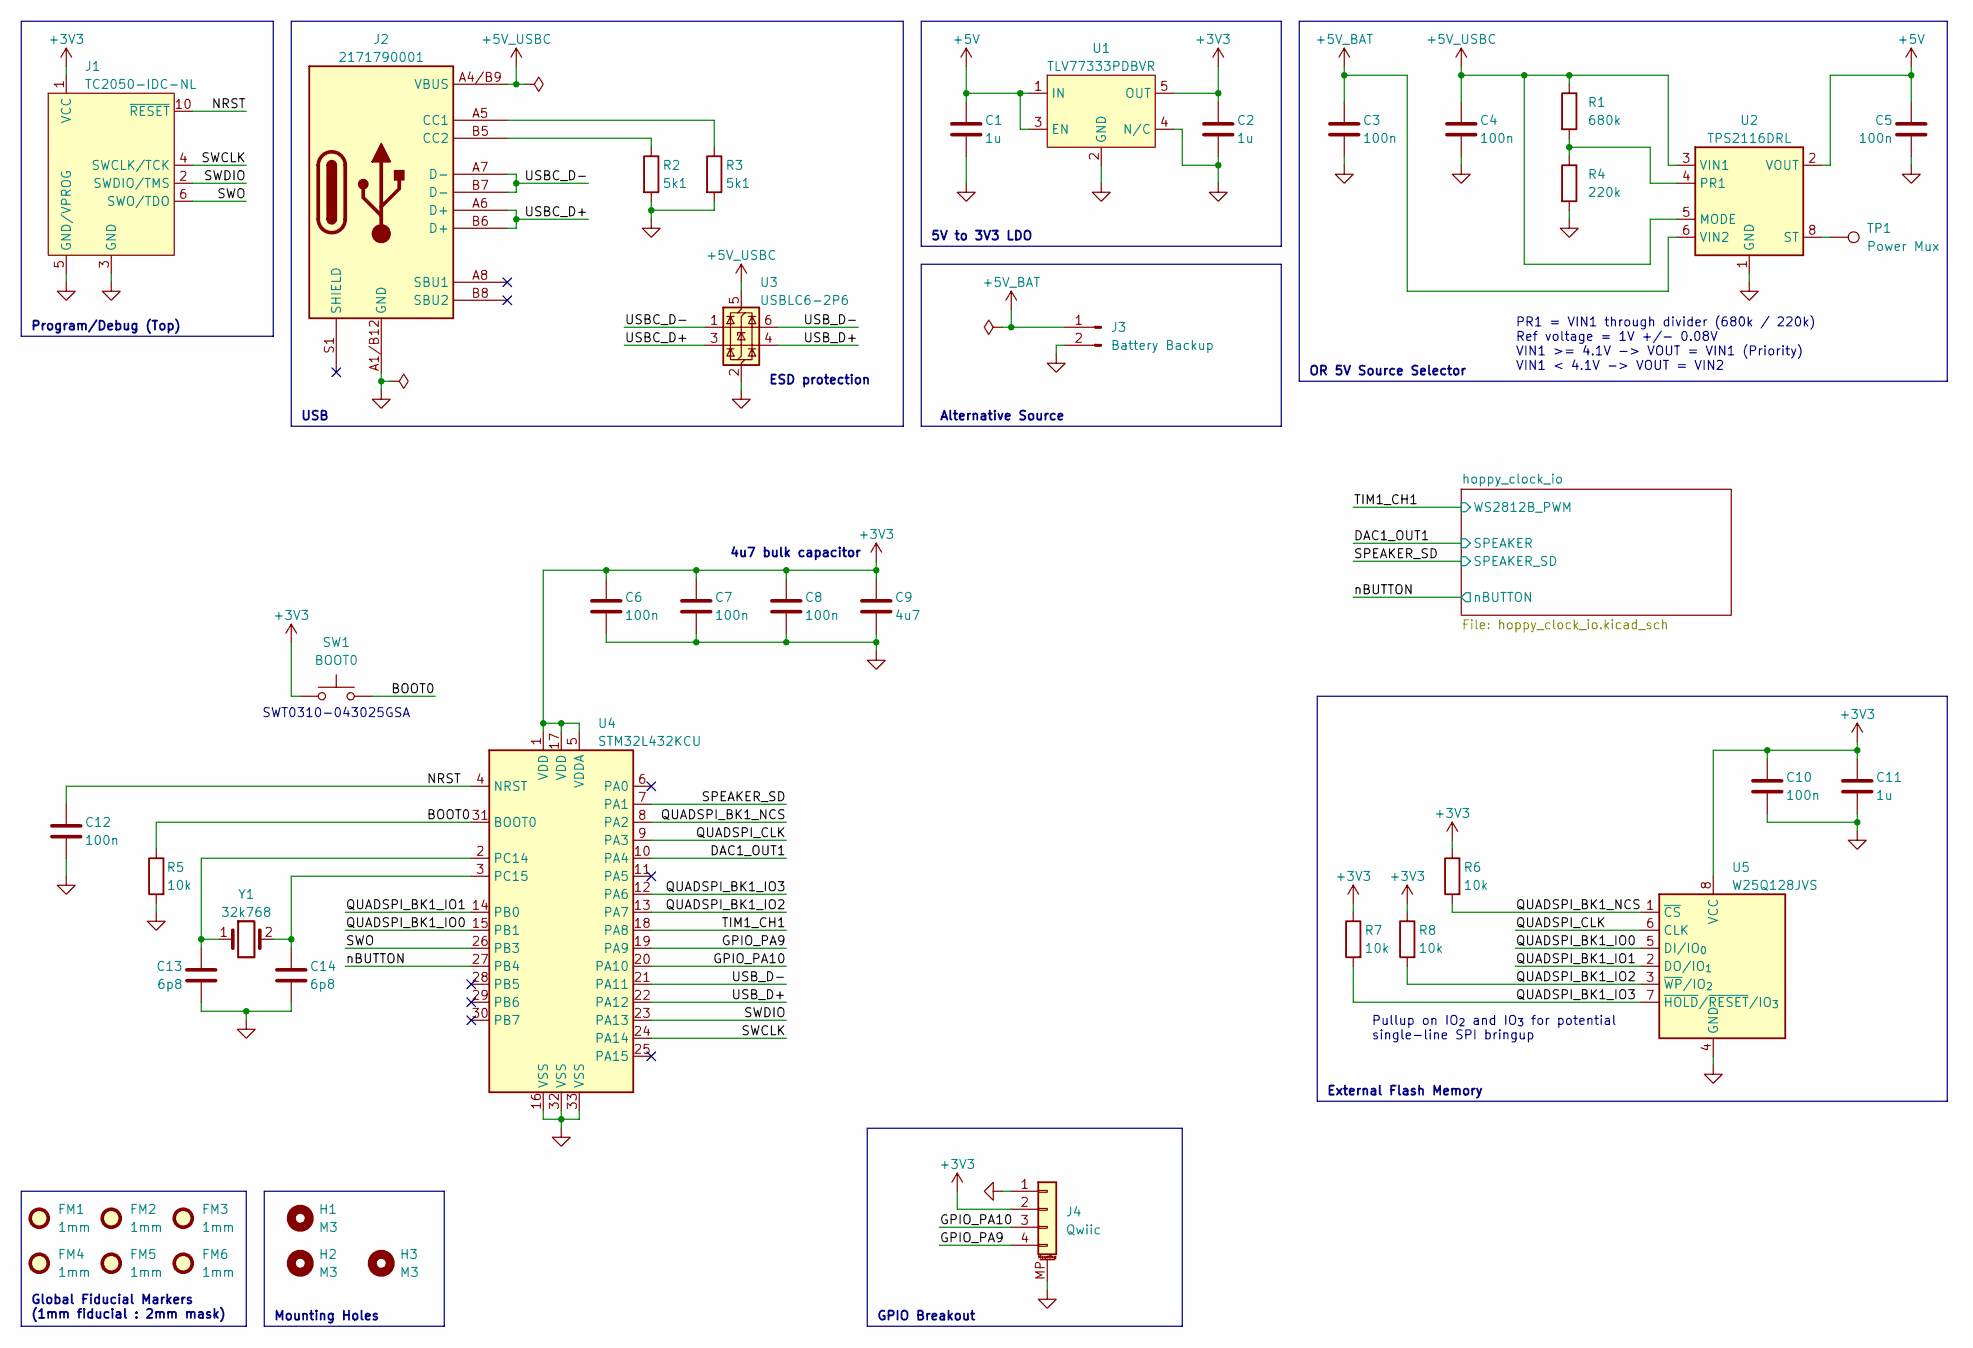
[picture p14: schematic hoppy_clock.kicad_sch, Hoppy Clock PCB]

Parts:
C1, C2, C11: 1u; C_0603_1608Metric
C3, C4, C5, C6, C7, C8, C10, C12: 100n; C_0603_1608Metric
C9: 4u7; C_0603_1608Metric
C13, C14: 6p8; C_0402_1005Metric
FM1, FM2, FM3, FM4, FM5, FM6: 1mm; Fiducial_1mm_Mask2mm
H1, H2, H3: M3; MountingHole_3.2mm_M3
J1: TC2050-IDC-NL; tag_connect_tc2050-idc-nl; Manufacturer Part Number TC2050-IDC-NL
J2: 2171790001; molex_2171790001_usb_c_16p; Manufacturer Part Number 2171790001
J3: Battery Backup; JST_XH_B2B-XH-A_1x02_P2.50mm_Vertical
J4: Qwiic; JST_SH_SM04B-SRSS-TB_1x04-1MP_P1.00mm_Horizontal
R1: 680k; R_0603_1608Metric
R2, R3: 5k1; R_0603_1608Metric
R4: 220k; R_0603_1608Metric
R5, R6, R7, R8: 10k; R_0603_1608Metric
SW1: BOOT0; swt0310-0430xxgsa
TP1: Power Mux; TestPoint_Pad_D2.0mm
U1: TLV77333PDBVR; sot-23_5; Manufacturer Part Number TLV77333PDBVR
U2: TPS2116DRL; SOT-583-8
U3: USBLC6-2P6; SOT-666
U4: STM32L432KCU; QFN-32-1EP_5x5mm_P0.5mm_EP3.45x3.45mm; Manufacturer Part Number STM32L432KCU6
U5: W25Q128JVS; SOIC-8_5.3x5.3mm_P1.27mm
Y1: 32k768; ecs_ecx-34r; Manufacturer Part Number ECS-.327-6-34R-C-TR

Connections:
+3V3: C2.1, C6.1, C7.1, C8.1, C9.1, C10.1, C11.1, J1.1 (VCC), J4.2, R6.1, R7.1, R8.1, SW1.1, U1.5 (OUT), U4.1 (VDD), U4.5 (VDDA), U4.17 (VDD), U5.8 (VCC); also elsewhere on the board
+5V: C1.1, C5.1, U1.1 (IN), U1.3 (EN), U2.2 (VOUT), U2.7 (VOUT); also elsewhere on the board
+5V_BAT: C3.1, J3.1, U2.6 (VIN2)
+5V_USBC: C4.1, J2.A4/B9 (VBUS), J2.B4/A9 (VBUS), R1.1, U2.3 (VIN1), U2.5 (MODE), U3.5 (VBUS); also elsewhere on the board
/BOOT0: R5.1, SW1.2, U4.31 (BOOT0)
/DAC1_OUT1: U4.10 (PA4); also elsewhere on the board
/GPIO_PA9: J4.4, U4.19 (PA9)
/GPIO_PA10: J4.3, U4.20 (PA10)
/NRST: C12.2, J1.10 (~RESET), U4.4 (NRST)
/QUADSPI_BK1_IO0: U4.15 (PB1), U5.5 (DI/IO_{0})
/QUADSPI_BK1_IO1: U4.14 (PB0), U5.2 (DO/IO_{1})
/QUADSPI_BK1_IO2: R8.2, U4.13 (PA7), U5.3 (~WP/IO_{2})
/QUADSPI_BK1_IO3: R7.2, U4.12 (PA6), U5.7 (~HOLD/~RESET/IO_{3})
/QUADSPI_BK1_NCS: R6.2, U4.8 (PA2), U5.1 (~CS)
/QUADSPI_CLK: U4.9 (PA3), U5.6 (CLK)
/SPEAKER_SD: U4.7 (PA1); also elsewhere on the board
/SWCLK: J1.4 (SWCLK/TCK), U4.24 (PA14)
/SWDIO: J1.2 (SWDIO/TMS), U4.23 (PA13)
/SWO: J1.6 (SWO/TDO), U4.26 (PB3)
/TIM1_CH1: U4.18 (PA8); also elsewhere on the board
/USBC_D+: J2.A6 (D+), J2.B6 (D+), U3.3 (I/O2)
/USBC_D-: J2.A7 (D-), J2.B7 (D-), U3.1 (I/O1)
/USB_D+: U3.4 (I/O2), U4.22 (PA12)
/USB_D-: U3.6 (I/O1), U4.21 (PA11)
/nBUTTON: U4.27 (PB4); also elsewhere on the board
GND: C1.2, C2.2, C3.2, C4.2, C5.2, C6.2, C7.2, C8.2, C9.2, C10.2, C11.2, C12.1, C13.2, C14.2, J1.3 (GND), J1.5 (GND/VPROG), J2.A1/B12 (GND), J2.B1/A12 (GND), J3.2, J4.1, J4.MP (MountPin), R2.2, R3.2, R4.2, R5.2, U1.2 (GND), U1.4 (N/C), U2.1 (GND), U3.2 (GND), U4.16 (VSS), U4.32 (VSS), U4.33 (VSS), U5.4 (GND); also elsewhere on the board
unnamed: J2.A5 (CC1), R3.1
unnamed: J2.B5 (CC2), R2.1
unnamed: R1.2, R4.1, U2.4 (PR1)
unnamed: TP1.1 (1_1), U2.8 (ST)
unnamed: C13.1, U4.2 (PC14), Y1.1
unnamed: C14.1, U4.3 (PC15), Y1.2

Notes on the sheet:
Global Fiducial Markers (1mm fiducial : 2mm mask)
Mounting Holes
5V to 3V3 LDO
USB
Program/Debug (Top)
Alternative Source
Pullup on IO_{2} and IO_{3} for potential single-line SPI bringup
External Flash Memory
GPIO Breakout
4u7 bulk capacitor
PR1 = VIN1 through divider (680k / 220k) Ref voltage = 1V +/- 0.08V VIN1 >= 4.1V -> VOUT = VIN1 (Priority) VIN1 < 4.1V -> VOUT = VIN2
OR 5V Source Selector
ESD protection
SWT0310-043025GSA

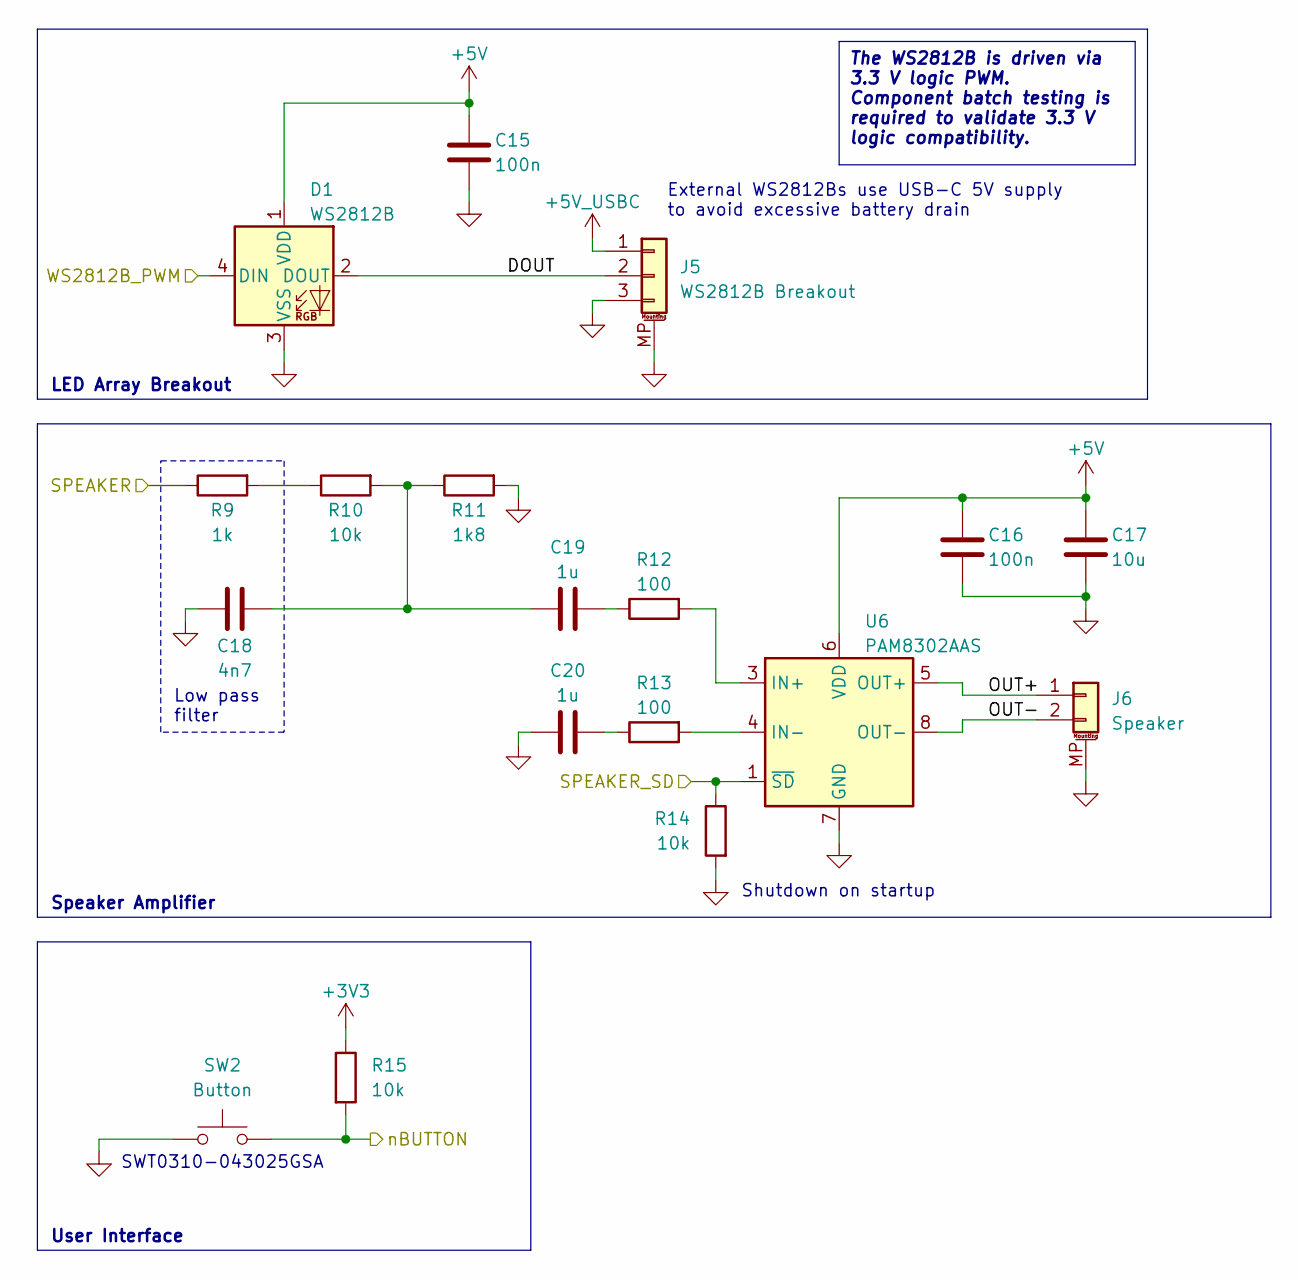
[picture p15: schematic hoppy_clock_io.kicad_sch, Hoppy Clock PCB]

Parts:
C15, C16: 100n; C_0603_1608Metric
C17: 10u; C_0603_1608Metric
C18: 4n7; C_0603_1608Metric
C19, C20: 1u; C_0603_1608Metric
D1: WS2812B; LED_WS2812B_PLCC4_5.0x5.0mm_P3.2mm
J5: WS2812B Breakout; JST_PH_S3B-PH-SM4-TB_1x03-1MP_P2.00mm_Horizontal
J6: Speaker; JST_PH_S2B-PH-SM4-TB_1x02-1MP_P2.00mm_Horizontal
R9: 1k; R_0603_1608Metric
R10, R14, R15: 10k; R_0603_1608Metric
R11: 1k8; R_0603_1608Metric
R12, R13: 100; R_0603_1608Metric
SW2: Button; swt0310-0430xxgsa
U6: PAM8302AAS; MSOP-8_3x3mm_P0.65mm

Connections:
+3V3: R15.1; also elsewhere on the board
+5V: C15.1, C16.1, C17.1, D1.1 (VDD), U6.6 (VDD); also elsewhere on the board
+5V_USBC: J5.1; also elsewhere on the board
/DAC1_OUT1: R9.1; also elsewhere on the board
/SPEAKER_SD: R14.1, U6.1 (~SD); also elsewhere on the board
/TIM1_CH1: D1.4 (DIN); also elsewhere on the board
/hoppy_clock_io/DOUT: D1.2 (DOUT), J5.2
/hoppy_clock_io/OUT+: J6.1, U6.5 (OUT+)
/hoppy_clock_io/OUT-: J6.2, U6.8 (OUT-)
/nBUTTON: R15.2, SW2.2; also elsewhere on the board
GND: C15.2, C16.2, C17.2, C18.2, C20.1, D1.3 (VSS), J5.3, J5.MP (MountPin), J6.MP (MountPin), R11.2, R14.2, SW2.1, U6.7 (GND); also elsewhere on the board
unnamed: C18.1, C19.1, R10.2, R11.1
unnamed: C19.2, R12.1
unnamed: C20.2, R13.1
unnamed: R9.2, R10.1
unnamed: R12.2, U6.3 (IN+)
unnamed: R13.2, U6.4 (IN-)

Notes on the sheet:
Speaker Amplifier
Shutdown on startup
Low pass filter
User Interface
SWT0310-043025GSA
LED Array Breakout
External WS2812Bs use USB-C 5V supply to avoid excessive battery drain
The WS2812B is driven via 3.3 V logic PWM. Component batch testing is required to validate 3.3 V logic compatibility.

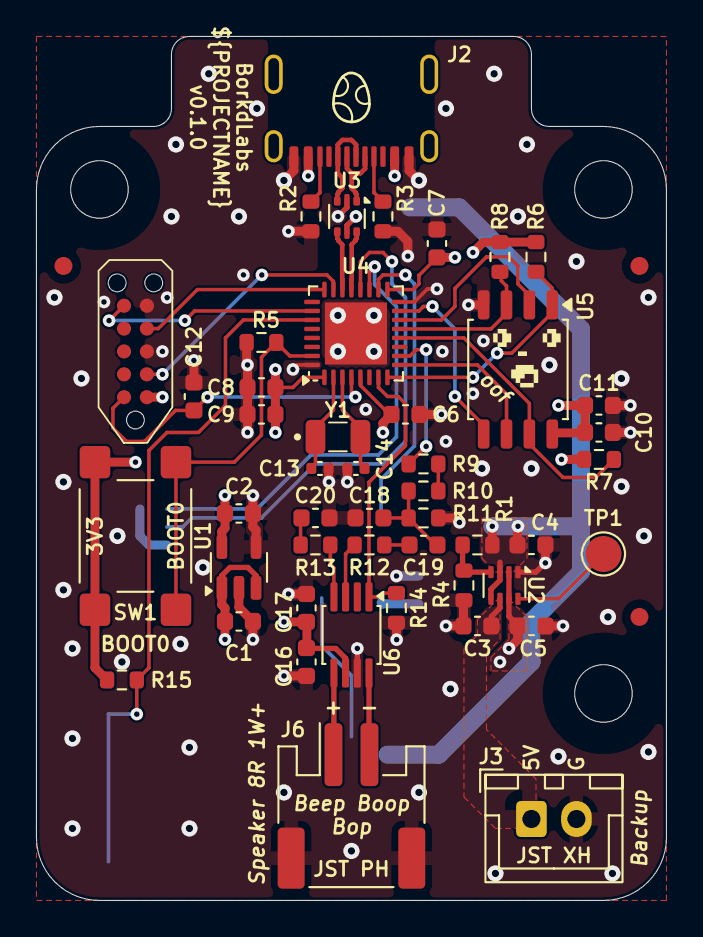
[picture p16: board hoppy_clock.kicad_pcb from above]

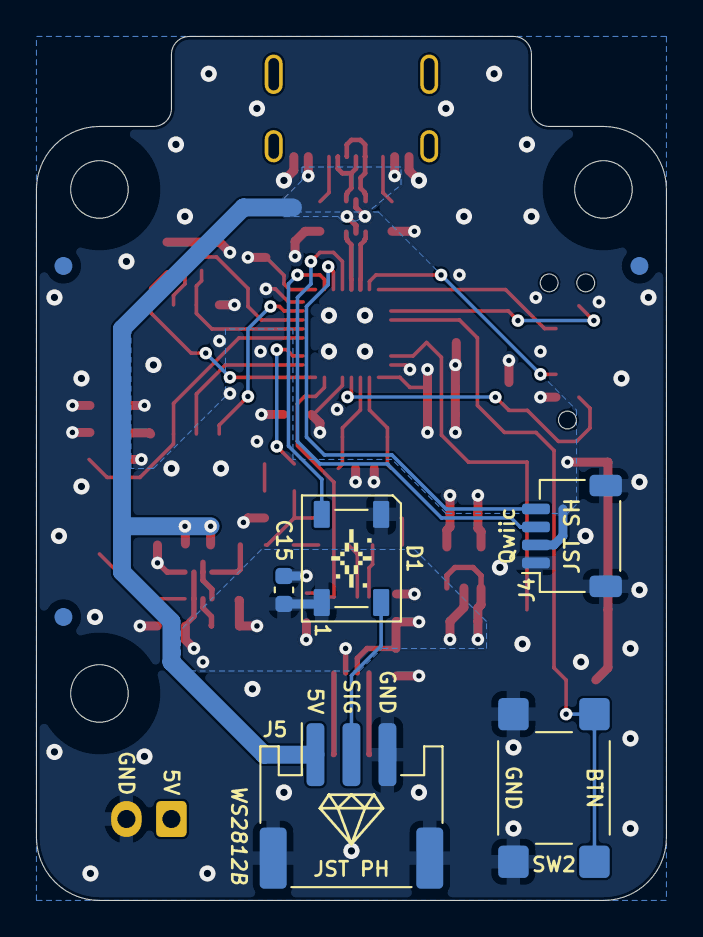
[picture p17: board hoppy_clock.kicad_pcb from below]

Board: 4 copper layers, 35.0 x 48.0 mm, 61 parts (8 on the bottom side), 41 nets.

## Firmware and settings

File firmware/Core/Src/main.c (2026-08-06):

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
/* Includes ------------------------------------------------------------------*/
#include "main.h"
#include "usb_device.h"

/* USER CODE BEGIN Includes */
#include "init.h"
#include "rtc.h"
#include "run.h"
/* USER CODE END Includes */

ADC_HandleTypeDef hadc1;
DMA_HandleTypeDef hdma_adc1;

DAC_HandleTypeDef hdac1;
DMA_HandleTypeDef hdma_dac_ch1;

QSPI_HandleTypeDef hqspi;
DMA_HandleTypeDef hdma_quadspi;

RTC_HandleTypeDef hrtc;

TIM_HandleTypeDef htim1;
TIM_HandleTypeDef htim2;
TIM_HandleTypeDef htim6;
DMA_HandleTypeDef hdma_tim1_ch1;

void SystemClock_Config(void);
void PeriphCommonClock_Config(void);
static void MX_GPIO_Init(void);
static void MX_DMA_Init(void);
static void MX_DAC1_Init(void);
static void MX_QUADSPI_Init(void);
static void MX_RTC_Init(void);
static void MX_TIM1_Init(void);
static void MX_ADC1_Init(void);
static void MX_TIM6_Init(void);
static void MX_TIM2_Init(void);
/**
  * @brief  The application entry point.
  * @retval int
  */
int main(void)
{

  /* MCU Configuration--------------------------------------------------------*/

  /* Reset of all peripherals, Initializes the Flash interface and the Systick. */
  HAL_Init();

  /* Configure the system clock */
  SystemClock_Config();

  /* Configure the peripherals common clocks */
  PeriphCommonClock_Config();

  /* Initialize all configured peripherals */
  MX_GPIO_Init();
  MX_DMA_Init();
  MX_DAC1_Init();
  MX_QUADSPI_Init();
  MX_RTC_Init();
  MX_TIM1_Init();
  MX_ADC1_Init();
  MX_TIM6_Init();
  MX_USB_DEVICE_Init();
  MX_TIM2_Init();
  /* Infinite loop */
  /* USER CODE BEGIN WHILE */
  hoppy_clock_init();

  while (1) {
    // float temperature = get_mcu_temp(); // TODO: Internal temp reading.
    hoppy_clock_run();
    /* USER CODE END WHILE */

    /* USER CODE BEGIN 3 */
  }
  /* USER CODE END 3 */
}

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


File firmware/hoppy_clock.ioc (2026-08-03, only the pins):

Mcu.UserName=STM32L432KCUx
PA1.Signal=GPIO_Output
PA11.Signal=USB_DM
PA12.Signal=USB_DP
PA2.Signal=QUADSPI_BK1_NCS
PA3.Signal=QUADSPI_CLK
PA4.Signal=COMP_DAC11_group
PA6.Signal=QUADSPI_BK1_IO3
PA7.Signal=QUADSPI_BK1_IO2
PA8.Signal=S_TIM1_CH1
PB0.Signal=QUADSPI_BK1_IO1
PB1.Signal=QUADSPI_BK1_IO0

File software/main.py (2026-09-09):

"""Hoppy Clock USB CDC test tool.

Frame: [0xA5][cmd][len][payload...][crc8]   crc8 poly 0x07 over cmd+len+payload.
Response echoes cmd; payload[0] is a status byte (0 = OK).

Usage:
  python main.py [-p PORT] COMMAND [args...]

Examples:
  python main.py ping                       # Ping the device (default port).
  python main.py -p COM3 ping               # Ping on a specific port.
  python main.py -p /dev/ttyACM0 get-time   # Read the clock (Linux port).
  python main.py set-time                   # Sync device to local "now".
  python main.py set-led 0 60 0 0           # LED index 0 -> red (r g b, 0-255).
  python main.py set-led 0 green            # LED index 0 -> named colour.
  python main.py set-led-count 12           # Set LED count to 12.

  # Define light looks (effect + params) and the lamp idle:
  python main.py set-light 0 --effect solid --color warm --brightness 1
  python main.py set-light 1 --effect solid --color warm --brightness 5 --flicker 40
  python main.py set-lamp --on 1 --off 0         # off idle = dim ambient.

  # Animated effects (loop until the ring/lamp ends):
  python main.py set-light 3 --effect rainbow --period 4000 --spread 24 --brightness 5
  python main.py set-light 4 --effect breathe --color blue --period 3000 --brightness 5

  # --fade/--curve run on entry only, so to ramp a look both in and out set
  # them on that look and on whatever replaces it:
  python main.py set-light 3 --effect rainbow --period 4000 --fade 2500 --curve ease
  python main.py set-light 0 --effect solid --brightness 0 --fade 2500 --curve ease

  # Sounds default to 16-bit PCM @ 16 kHz (2 slots, ~4 min each):
  python main.py upload-sound 0 --tone 880 --seconds 1 --gain 0.05
  python main.py upload-sound 1 song.mp3 --gain 0.6  # needs ffmpeg
  python main.py upload-sound 1 song.mp3 --gain 0.6 --trim 60  # first 60s
  python main.py sound-info 1
  python main.py play-sound 1                     # play it now
  python main.py stop-sound                       # stop playback
  python main.py set-button-song 1                # long-press plays sound 1

  # Alarms: build up as many as you like (add-alarm keeps existing ones).
  python main.py add-alarm --at 08:00 --days weekdays --sound 1 --light 2 --fade 20
  python main.py add-alarm --at 09:30 --days weekends --sound 1 --light 2
  python main.py add-alarm --at 07:00 --dom 1              # monthly, the 1st
  python main.py set-alarm --in 1 --sound 1 --light 2 --fade 20  # test: 1 min out
  python main.py list-alarms                               # numbered list
  python main.py remove-alarm 2                            # delete by index
  python main.py clear-alarms                              # delete all

  python main.py wipe            # factory reset (erase all config + sounds)
  python main.py wipe --full     # also scrub the raw audio bytes (slow)
"""

import argparse
import datetime
import math
import os
import shutil
import struct
import subprocess
import sys
import time
import wave
import zlib

import serial

DEFAULT_PORT = "COM1"

SOF = 0xA5
STATUS_OK = 0x00

# Command IDs (must match usb_cmd.h).
CMD_PING = 0x01
CMD_SET_TIME = 0x10
CMD_GET_TIME = 0x11
CMD_SET_LED = 0x20
CMD_CFG_BEGIN = 0x30
CMD_CFG_SET_ALARM = 0x31
CMD_CFG_COMMIT = 0x32
CMD_CFG_GET_COUNT = 0x33
CMD_CFG_GET_ALARM = 0x34
CMD_CFG_SET_LIGHT = 0x35
CMD_CFG_SET_LAMP = 0x36
CMD_CFG_GET_LIGHT = 0x37
CMD_CFG_SET_LEDS = 0x38
CMD_CFG_SET_BTN = 0x39
CMD_SND_BEGIN = 0x40
CMD_SND_DATA = 0x41
CMD_SND_END = 0x42
CMD_SND_INFO = 0x43
CMD_SND_PLAY = 0x44
CMD_SND_STOP = 0x45
CMD_WIPE = 0x50

# Alarm record (must match manifest.h): 12 bytes, little-endian.
# flags, day, h, m, s, timeout, sound, light, sound_fade_s, reserved(2).
ALARM_STRUCT = "<BBBBBHBBBBB"
ALARM_FLAG_ENABLED = 0x01
ALARM_FLAG_MONTHLY = 0x02
MANIFEST_MAX_ALARMS = 64  # Must match manifest.h.

# Light sequence (must match manifest.h): 12 bytes, little-endian.
# effect, r, g, b, brightness, period_ms, curve, spread, fade_ms, flicker.
LIGHT_STRUCT = "<BBBBBHBBHB"
LIGHT_FX = {"solid": 0, "rainbow": 1, "sweep": 2, "breathe": 3}
# Shapes the fade for every effect, not just solid.
LIGHT_CURVES = {"linear": 0, "ease": 1}
# Base colours for light looks (full-intensity hues; brightness scales them).
BASE_COLORS = {
    "warm": (255, 200, 120),
    "white": (255, 255, 255),
    "red": (255, 0, 0),
    "green": (0, 255, 0),
    "blue": (0, 0, 255),
    "amber": (255, 140, 0),
}
DAY_BITS = {
    "mon": 0,
    "tue": 1,
    "wed": 2,
    "thu": 3,
    "fri": 4,
    "sat": 5,
    "sun": 6,
}
DAY_GROUPS = {
    "daily": "mon,tue,wed,thu,fri,sat,sun",
    "weekdays": "mon,tue,wed,thu,fri",
    "weekends": "sat,sun",
}

# Audio formats (must match sound.h).
SND_FORMAT_PCM_U8 = 0x00
SND_FORMAT_PCM_S16 = 0x01
SND_FORMATS = {"s16": SND_FORMAT_PCM_S16, "u8": SND_FORMAT_PCM_U8}
SND_BYTES_PER_SAMPLE = {SND_FORMAT_PCM_U8: 1, SND_FORMAT_PCM_S16: 2}
SND_RATE_HZ = 16000  # Default rate; 16-bit PCM @ 16 kHz is the song target.
SND_CHUNK = 64  # Data chunk size; must be <= firmware USB_CMD_MAX_PAYLOAD.
SND_SLOT_BYTES = 7680 * 1024  # Per-sound flash slot (firmware SOUND_SLOT_SIZE).

# Convenience colour names for `set-led`.
COLORS = {
    "warm": (40, 40, 30),
    "red": (60, 0, 0),
    "green": (0, 60, 0),
    "blue": (0, 0, 60),
    "white": (60, 60, 60),
    "off": (0, 0, 0),
}


def crc8(data: bytes) -> int:
    crc = 0
    for b in data:
        crc ^= b
        for _ in range(8):
            crc = (
                ((crc << 1) ^ 0x07) & 0xFF
                if (crc & 0x80)
                else (crc << 1) & 0xFF
            )
    return crc


def build_frame(cmd: int, payload: bytes = b"") -> bytes:
    body = bytes([cmd, len(payload)]) + payload
    return bytes([SOF]) + body + bytes([crc8(body)])


def read_frame(ser, timeout=1.0):
    """Sync on SOF and read one full, CRC-checked frame.

    Returns:
        (cmd, payload) or None.
    """
    end = time.time() + timeout
    # Find SOF.
    while time.time() < end:
        b = ser.read(1)
        if b and b[0] == SOF:
            break
    else:
        return None
    hdr = ser.read(2)  # (cmd, len).
    if len(hdr) < 2:
        return None
    cmd, length = hdr[0], hdr[1]
    payload = ser.read(length)
    crc = ser.read(1)
    if len(payload) != length or len(crc) != 1:
        return None
    if crc[0] != crc8(bytes([cmd, length]) + payload):
        print("  ! bad CRC")
        return None
    return cmd, payload


def txn(ser, cmd, payload=b"", timeout=1.0):
    ser.reset_input_buffer()
    ser.write(build_frame(cmd, payload))
    return read_frame(ser, timeout)


def ok(payload) -> bool:
    return len(payload) >= 1 and payload[0] == STATUS_OK


def _status(r) -> str:
    return "OK" if r and ok(r[1]) else f"FAIL ({r})"
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

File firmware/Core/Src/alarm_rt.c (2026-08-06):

/*******************************************************************************
 * @file alarm_rt.c
 * @brief Alarm runtime: arms RTC Alarm A and drives the ring (LED ramp).
 *******************************************************************************
 * @note:
 * Ties the pure scheduling logic in alarm.h to the hardware. It keeps RTC
 * Alarm A programmed for the soonest upcoming alarm, when the alarm fires its
 * interrupt callback flags alarm_rt_notify_fired(), and the scheduler task
 * alarm_rt_task() picks a matching alarm, ramps LED 0 up to its brightness over
 * its ramp time, holds until the timeout (or a long-press cancel), then re-arms
 * the next alarm.
 *
 * Sound playback is not yet wired (the sound asset region is a later step),
 * alarm_rt_task() marks where sound_id would start/stop. Low-power sleep is
 * likewise out of scope here: the runtime assumes the CPU stays awake.
 *******************************************************************************
 */

/** Includes. *****************************************************************/

#include "alarm_rt.h"
#include "alarm.h"
#include "light.h"
#include "manifest.h"
#include "rtc.h"
#include "sound.h"

/** Private variables. ********************************************************/

// Set by the RTC Alarm A ISR callback, consumed by alarm_rt_task().
static volatile bool s_fired = false;

// Ring state. The LED look is owned by the light module; here we only track the
// auto-quiet timeout (ms, seconds scale up past 16 bits) against HAL_GetTick().
static bool s_ringing = false;
static uint32_t s_ring_start_ms = 0u;
static uint32_t s_ring_timeout_ms = 0u; // 0 = no auto-quiet (cancel only).

/** Private functions. ********************************************************/

/**
 * @brief Read the current RTC date/time into alarm_time_t field form.
 */
static void read_now(alarm_time_t *now) {
  get_date_time_fields(&now->year, &now->month, &now->date, &now->weekday,
                       &now->hour, &now->minute, &now->second);
}

/**
 * @brief End the current ring: stop sound, return the LED to the lamp idle.
 */
static void stop_ring(void) {
  s_ringing = false;
  sound_stop();         // No-op if this ring had no sound; also mutes the amp.
  light_lamp_reapply(); // Back to the current lamp on/off idle look.
}

/**
 * @brief Begin ringing for whichever enabled alarm matches now, then re-arm.
 */
static void start_ring(void) {
  // Never ring on the default 2000 calendar: if the clock isn't set, drop this
  // (stale) fire and leave Alarm A disarmed. This is redundant cover, a rearm
  // won't arm while unset, so this shouldn't be reached.
  if (rtc_is_unset()) {
    alarm_rt_rearm();
    return;
  }

  alarm_time_t now;
  read_now(&now);

  const manifest_t *m = manifest_get();
  for (uint16_t i = 0u; i < m->header.alarm_count; i++) {
    const alarm_record_t *a = &m->alarms[i];
    if (!alarm_record_matches(a, &now)) {
      continue;
    }
    s_ring_timeout_ms = (uint32_t)a->timeout_s * 1000u;
    s_ring_start_ms = HAL_GetTick();
    s_ringing = true;

    // Play the alarm's light look (LED-only ring if the id is unprogrammed).
    if (a->light_id < m->header.light_count) {
      light_play(&m->lights[a->light_id]);
    }

    // Preempt any button-press song so the alarm clearly takes over the speaker
    // (no-op if nothing is playing), then play the alarm's sound if one is
    // stored (sound_start owns the amp), fading in over sound_fade_s.
    sound_stop();
    sound_start(a->sound_id, (uint32_t)a->sound_fade_s * 1000u);
    break;
  }

  // The just-fired alarm's next occurrence rolls forward, so re-arm regardless
  // of whether a match was found (e.g. a stale interrupt).
  alarm_rt_rearm();
}

/**
 * @brief Advance the ring: honour the auto-quiet timeout.
 */
static void update_ring(void) {
  const uint32_t elapsed = HAL_GetTick() - s_ring_start_ms;
  if (s_ring_timeout_ms != 0u && elapsed >= s_ring_timeout_ms) {
    stop_ring();
  }
}

/** Public functions. *********************************************************/

void alarm_rt_init(void) {
  s_fired = false;
  s_ringing = false;
  alarm_rt_rearm();
}

void alarm_rt_rearm(void) {
  // STM32 Alarm A matches weekday/date + time only (not the year) so arming
  // while the RTC sits at its 2000 power-on default would fire alarms on a
  // bogus calendar. Keep it disarmed until the user sets the time.
  if (rtc_is_unset()) {
    HAL_RTC_DeactivateAlarm(&hrtc, RTC_ALARM_A);
    return;
  }

  alarm_time_t now;
  read_now(&now);

  alarm_next_t next;
  if (!alarm_next(manifest_get(), &now, &next)) {
    HAL_RTC_DeactivateAlarm(&hrtc, RTC_ALARM_A);
    return;
  }

  RTC_AlarmTypeDef alarm = {0};
  alarm.AlarmTime.Hours = next.hour;
  alarm.AlarmTime.Minutes = next.minute;
  alarm.AlarmTime.Seconds = next.second;
  alarm.AlarmTime.SubSeconds = 0u;
  alarm.AlarmTime.DayLightSaving = RTC_DAYLIGHTSAVING_NONE;
  alarm.AlarmTime.StoreOperation = RTC_STOREOPERATION_RESET;
  alarm.AlarmMask = RTC_ALARMMASK_NONE; // Match hours, minutes, seconds + day.
  alarm.AlarmSubSecondMask = RTC_ALARMSUBSECONDMASK_ALL;
  alarm.AlarmDateWeekDaySel = next.monthly ? RTC_ALARMDATEWEEKDAYSEL_DATE
                                           : RTC_ALARMDATEWEEKDAYSEL_WEEKDAY;
  alarm.AlarmDateWeekDay = next.day; // Date 1..31, or weekday Mon=1..Sun=7.
  alarm.Alarm = RTC_ALARM_A;

  HAL_RTC_SetAlarm_IT(&hrtc, &alarm, RTC_FORMAT_BIN);
}

void alarm_rt_task(void) {
  if (s_fired) {
    s_fired = false;
    start_ring();
  }
  if (s_ringing) {
    update_ring();
  }
}

void alarm_rt_notify_fired(void) { s_fired = true; }

bool alarm_rt_is_ringing(void) { return s_ringing; }

void alarm_rt_cancel(void) {
  if (s_ringing) {
    stop_ring();
  }
}

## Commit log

2026-07-16 Add initial local components
    [2169900001.stp, 2171790001.stp, QFN-32-1EP_5x5mm_P0.5mm_EP3.3x3.3mm.step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]
2026-07-16 Add WIP hardware and firmware (ioc)
    [hoppy_clock.kicad_pcb, hoppy_clock.kicad_sch, hoppy_clock_leds.kicad_sch]
2026-07-16 Add WIP schematic
    [hoppy_clock.kicad_sch, hoppy_clock_leds.kicad_sch, hoppy_clock_speaker.kicad_sch]
2026-07-16 Update minor resistor values
    [hoppy_clock.kicad_sch, hoppy_clock_speaker.kicad_sch]
2026-07-16 Additional PCB WIP, pass ERC
    [hoppy_clock.kicad_sch, hoppy_clock_leds.kicad_sch, hoppy_clock_speaker.kicad_sch]
2026-07-16 Reduce down to 3 mounting holes
    [hoppy_clock.kicad_sch]
2026-07-16 Add WIP PCB layout
    [hoppy_clock.kicad_pcb, hoppy_clock.kicad_sch, hoppy_clock_leds.kicad_sch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]
2026-07-16 Add WIP component group routing
    [hoppy_clock.kicad_pcb]
2026-07-17 Add continued WIP layout/routing
    [hoppy_clock.kicad_pcb, hoppy_clock.kicad_sch]
2026-07-17 Major redesign (pass ERC)
    [hoppy_clock.kicad_sch, hoppy_clock_leds.kicad_sch, hoppy_clock_speaker.kicad_sch]
2026-07-17 Add WIP layout
    [hoppy_clock.kicad_pcb, hoppy_clock.kicad_sch]
2026-07-17 WIP layout (again)
    [hoppy_clock.kicad_pcb, hoppy_clock.kicad_sch]
2026-07-17 Add WIP (3) and add SMD switch component
    [hoppy_clock.kicad_pcb, hoppy_clock.kicad_sch, swt0310-043025gsa.stp]
2026-07-17 Swap to Qwiic, add power mux and WIP layout
    [hoppy_clock.kicad_pcb, hoppy_clock.kicad_sch]
2026-07-17 Add WIP layout (pain)
    [hoppy_clock.kicad_pcb, hoppy_clock.kicad_sch, hoppy_clock_io.kicad_sch]
2026-07-18 WIP layout
    [hoppy_clock.kicad_pcb, hoppy_clock.kicad_sch, hoppy_clock_io.kicad_sch]
2026-07-18 Pass ERC and DRC
    [hoppy_clock.kicad_pcb, hoppy_clock.kicad_sch]
2026-07-18 PCB cleanup
    [hoppy_clock.kicad_pcb, hoppy_clock.kicad_sch, hoppy_clock_io.kicad_sch]
2026-07-18 Add stitching vias
    [hoppy_clock.kicad_pcb]
2026-07-18 Minor cleanup
    [hoppy_clock.kicad_pcb]
2026-07-20 Add LPC on speaker amp and cleanup
    [hoppy_clock.kicad_pcb, hoppy_clock_io.kicad_sch]
2026-07-20 Cleanup inner layer via pads
    [hoppy_clock.kicad_pcb]
2026-07-20 Cleanup and prep release
    [hoppy_clock.kicad_pcb, hoppy_clock.kicad_sch, hoppy_clock_io.kicad_sch]
2026-07-21 Add initial WS2812B led
2026-07-23 Fix include guard naming
    [ws2812b_hal_pwm.h]
2026-07-23 Add initial temperature and VREFINT sense
2026-07-23 Cleanup PAM8302A drivers
2026-07-23 Add initial NOR flash memory drivers
2026-07-23 Add local 3D models for partial KiCad footprints
    [S2B-PH-SM4-TB.STEP, S3B-PH-SM4-TB.STEP, hoppy_clock.kicad_pcb]
2026-07-25 Update DNP fields and add PCB renders
    [hoppy_clock.kicad_pcb, hoppy_clock.kicad_sch, hoppy_clock_io.kicad_sch]
2026-07-26 Fix the WS2812B breakout connector pinout
    [hoppy_clock.kicad_pcb, hoppy_clock.kicad_sch, hoppy_clock_io.kicad_sch]
2026-07-26 Add improved button EXTI4 config
2026-07-26 Add initial scheduler and button and cleanup main
2026-08-02 Add USB LED command
2026-08-02 Add initial LED startup test sequence
2026-08-02 Add voltage div for improved supply mux threshold
    [hoppy_clock.kicad_pcb, hoppy_clock.kicad_sch, hoppy_clock_io.kicad_sch]
2026-08-02 Add initial custom LED control
2026-08-02 Minor PCB cleanup
    [hoppy_clock.kicad_pcb]
2026-08-03 Fix WS2812B DMA configuration
    [hoppy_clock.ioc]
2026-08-03 Swap to longer 12-bit sound and bump USB payloads
    [sound.c]
2026-08-03 Fix USB NVIC priority
    [hoppy_clock.ioc]
2026-08-03 Remove beep on long button press (test code)
2026-08-03 Add LED index 0 blinking for RTC unset
2026-08-06 Add initial power mode control
2026-08-06 Fix alarms firing on bogus RTC after power loss
    [alarm_rt.c, main.c, rtc.c]
2026-08-06 Fix STOP2 clock recovery
    [power.c]
2026-08-07 Drop USB pull-up in STOP2 to fix reconnect
    [power.c]
2026-08-12 Swap user button to matching SMD button
    [hoppy_clock.kicad_pcb, hoppy_clock_io.kicad_sch]
2026-08-12 Move SMD right angle connectors closer to edge cut
    [hoppy_clock.kicad_pcb]
2026-08-13 Add missing user comments dimension
    [hoppy_clock.kicad_pcb]
2026-08-18 Cleanup silkscreen
    [hoppy_clock.kicad_pcb]
2026-08-18 Update PCB renders
2026-08-23 Split WS2812B connector 5V supply
    [hoppy_clock.kicad_pcb, hoppy_clock_io.kicad_sch]
2026-08-29 Add initial webapp WIP prototype
2026-08-29 Add PCBWay sponsorship and logo
2026-08-30 Add manual set LED control
2026-11-04 Add THT breakout for User button footprint
2026-11-04 Minor silkscreen cleanup

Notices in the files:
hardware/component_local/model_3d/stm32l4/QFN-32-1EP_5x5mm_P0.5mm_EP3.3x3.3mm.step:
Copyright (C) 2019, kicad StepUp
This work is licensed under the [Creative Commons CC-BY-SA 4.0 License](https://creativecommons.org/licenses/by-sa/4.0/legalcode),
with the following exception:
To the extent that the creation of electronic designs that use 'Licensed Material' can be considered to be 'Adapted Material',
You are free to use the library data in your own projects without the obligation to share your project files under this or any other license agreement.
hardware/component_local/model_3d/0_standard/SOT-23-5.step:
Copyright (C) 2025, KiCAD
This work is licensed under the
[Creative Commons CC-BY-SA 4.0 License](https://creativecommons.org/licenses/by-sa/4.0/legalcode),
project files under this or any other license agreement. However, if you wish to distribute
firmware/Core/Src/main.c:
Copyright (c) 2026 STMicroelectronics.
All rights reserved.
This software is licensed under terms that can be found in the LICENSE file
